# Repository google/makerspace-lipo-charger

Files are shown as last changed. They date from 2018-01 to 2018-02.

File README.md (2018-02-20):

This is in the early stages of prototyping a multi-port 1S Li-po charger.

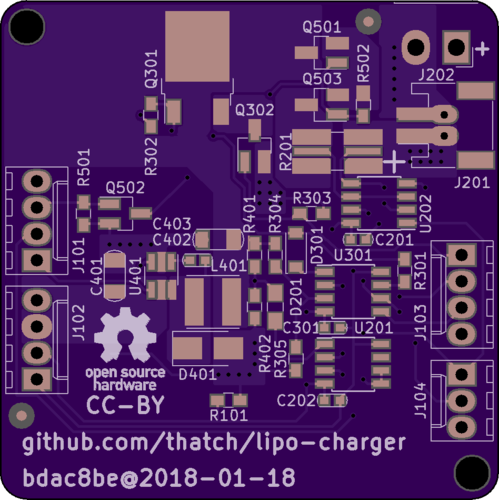
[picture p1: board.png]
Board render


Features include:

- Wide input voltage (approx 5-24V, untested)
- High charge current (up to ~2.5A, untested)
- Discharge circuit (to arbitrary voltage; connector is limiting factor --
  mosfet can do ~10A)
- (Upstream) microcontroller only involved in the slow loops ("is it charged
  yet?", not "is current limit hit?")
- Relatively inexpensive BOM (compared to all-in-one buck-based chargers)
- Relatively easy to solder (only one part smaller than SO-8 and 0603, no exposed pads)

Open questions:

- Do we need extra soft-start circuitry to avoid current spike at beginning of charge?
- Can we heatsink the discharge circuit so this stacks better (DPAK on back ground plane)?
- How small can we get this as a replaceable daughterboard?
- How will we mount it inside a case?
- Can we trust the sum of individual shunts for calculating used power budget?
- How will MCU stay alive while probing (or backing off)
- Is there a much better way to shut off discharge (second nmos is obvious, but expensive)

License: CC-BY 4.0 International

Disclaimer: This not an official Google product.

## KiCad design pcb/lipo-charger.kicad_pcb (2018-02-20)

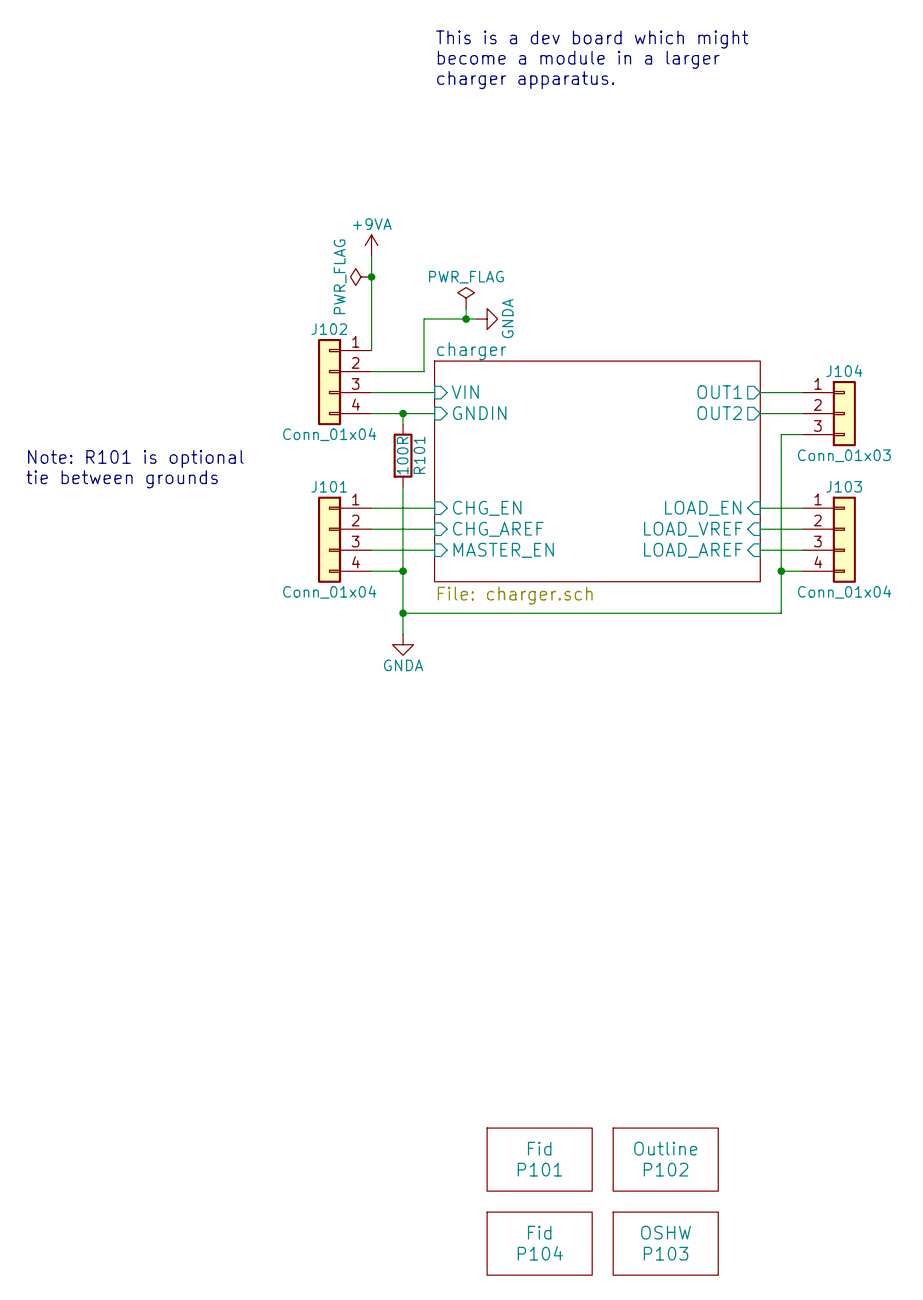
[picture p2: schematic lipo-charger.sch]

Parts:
J101, J102, J103: Conn_01x04; Molex_KK-6410-04_04x2.54mm_Straight
J104: Conn_01x03; Molex_KK-6410-03_03x2.54mm_Straight
P101, P104: Fid; Fiducial_1mm_Dia_2.54mm_Outer_CopperTop
P102: Outline; Board_Outline_48mm_Square
P103: OSHW; OSHW-Logo_7.5x8mm_SilkScreen
R101: 100R; R_0603_HandSoldering

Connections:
+9VA: J102.1; also elsewhere on the board
/charger/CHG_AREF: J101.2; also elsewhere on the board
/charger/CHG_EN: J101.1; also elsewhere on the board
/charger/GNDIN: J102.4, R101.1; also elsewhere on the board
/charger/LOAD_AREF: J103.3; also elsewhere on the board
/charger/LOAD_EN: J103.1; also elsewhere on the board
/charger/LOAD_VREF: J103.2; also elsewhere on the board
/charger/MASTER_EN: J101.3; also elsewhere on the board
/charger/OUT1: J104.1; also elsewhere on the board
/charger/OUT2: J104.2; also elsewhere on the board
/charger/VIN: J102.3; also elsewhere on the board
GNDA: J101.4, J102.2, J103.4, J104.3, R101.2; also elsewhere on the board

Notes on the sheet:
Note: R101 is optional tie between grounds
This is a dev board which might become a module in a larger charger apparatus.

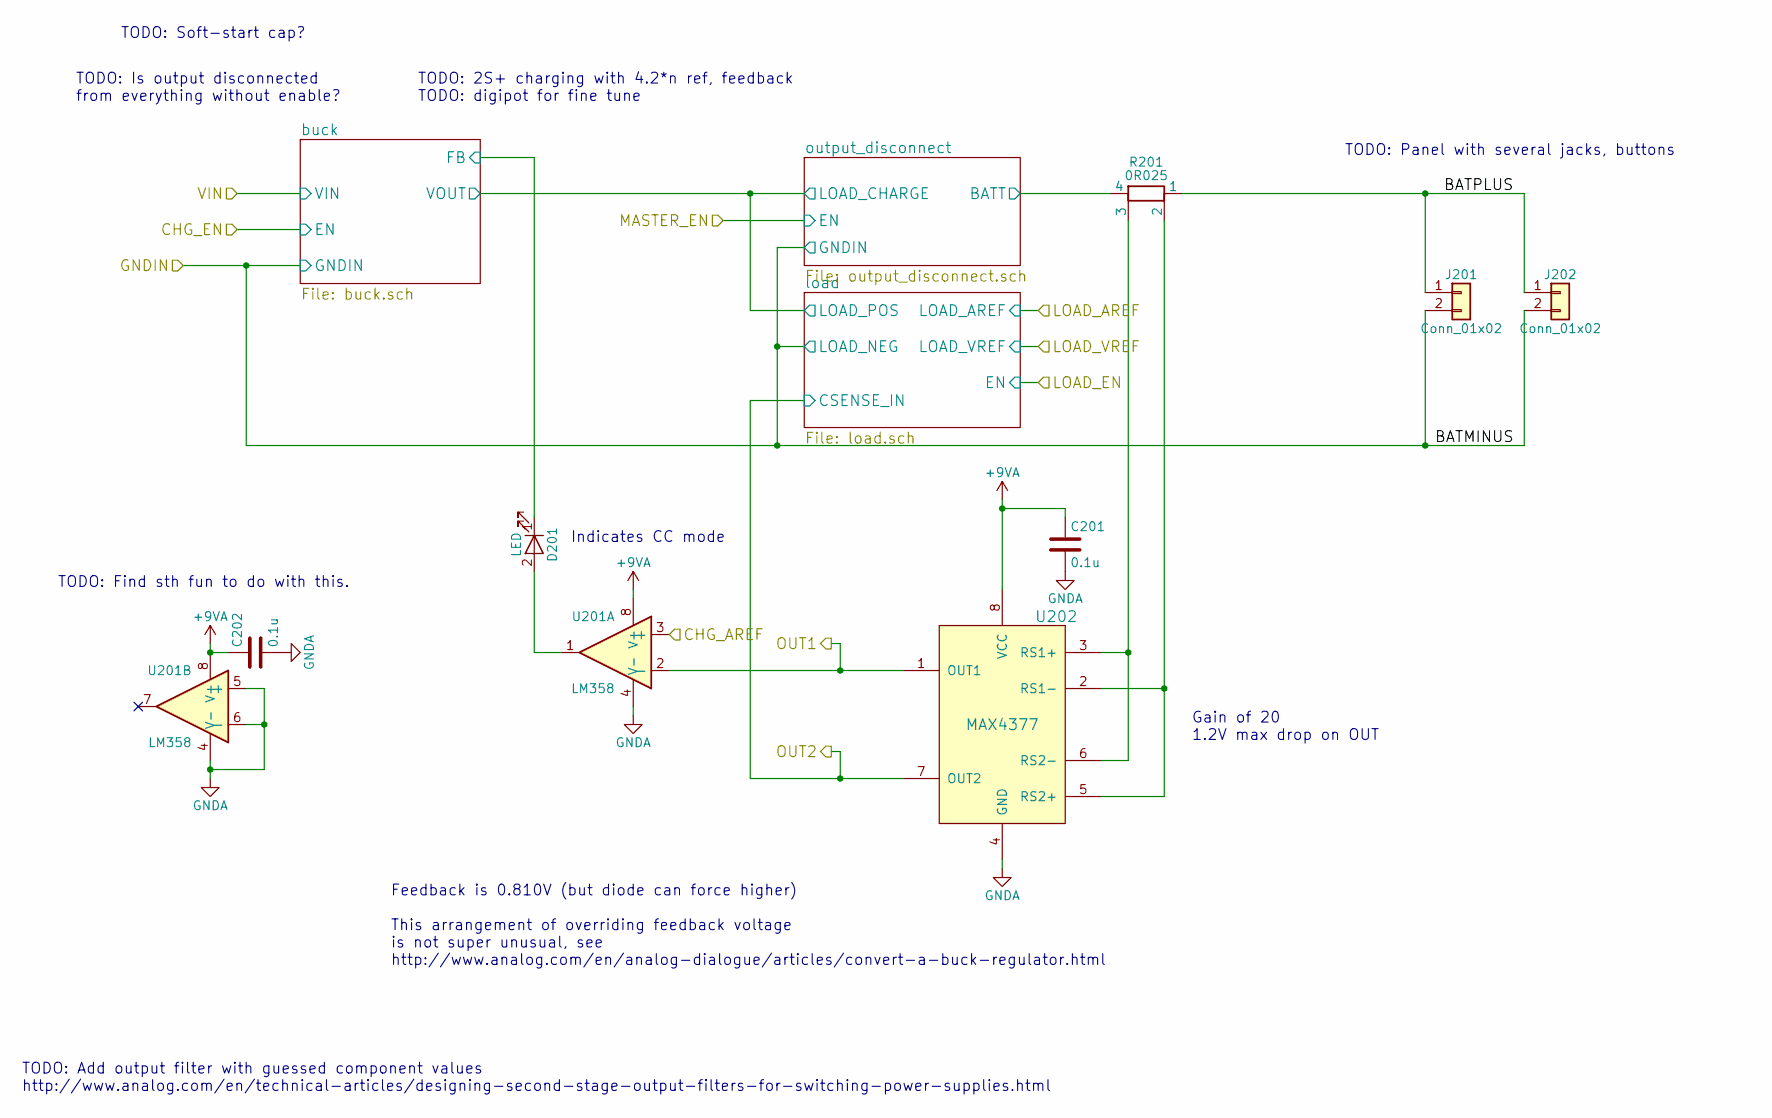
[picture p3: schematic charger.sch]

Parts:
C201, C202: 0.1u; C_0603
D201: LED; LED_0805_HandSoldering
J201: Conn_01x02; JST_PH_2_Combo
J202: Conn_01x02; JST_VH_B2PS-VH_2x2x3.96mm_Horizontal
R201: 0R025; R_2512_AD_Optimized
U201: LM358; SOIC-8_3.9x4.9mm_Pitch1.27mm
U202: MAX4377; SOIC-8_3.9x4.9mm_Pitch1.27mm; MPN MAX4377TASA+

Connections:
+9VA: C201.1, C202.1, U201.8 (V+), U202.8 (VCC); also elsewhere on the board
/charger/BATPLUS: J201.1, J202.1, R201.1
/charger/CHG_AREF: U201.3 (+); also elsewhere on the board
/charger/GNDIN: J201.2, J202.2; also elsewhere on the board
/charger/OUT1: U201.2 (-), U202.1 (OUT1); also elsewhere on the board
/charger/OUT2: U202.7 (OUT2); also elsewhere on the board
/charger/buck/FB: D201.1 (K); also elsewhere on the board
/charger/output_disconnect/BATT: R201.4; also elsewhere on the board
GNDA: C201.2, C202.2, U201.4 (V-), U201.5 (+), U201.6 (-), U202.4 (GND); also elsewhere on the board
unnamed: D201.2 (A), U201.1
unnamed: R201.2, U202.2 (RS1-), U202.5 (RS2+)
unnamed: R201.3, U202.3 (RS1+), U202.6 (RS2-)

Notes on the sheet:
Feedback is 0.810V (but diode can force higher) This arrangement of overriding feedback voltage is not super unusual, see http://www.analog.com/en/analog-dialogue/articles/convert-a-buck-regulator.html
TODO: Add output filter with guessed component values http://www.analog.com/en/technical-articles/designing-second-stage-output-filters-for-switching-power-supplies.html
TODO: Panel with several jacks, buttons
Indicates CC mode
TODO: Soft-start cap?
TODO: Is output disconnected from everything without enable?
Gain of 20 1.2V max drop on OUT
TODO: 2S+ charging with 4.2*n ref, feedback TODO: digipot for fine tune
TODO: Find sth fun to do with this.

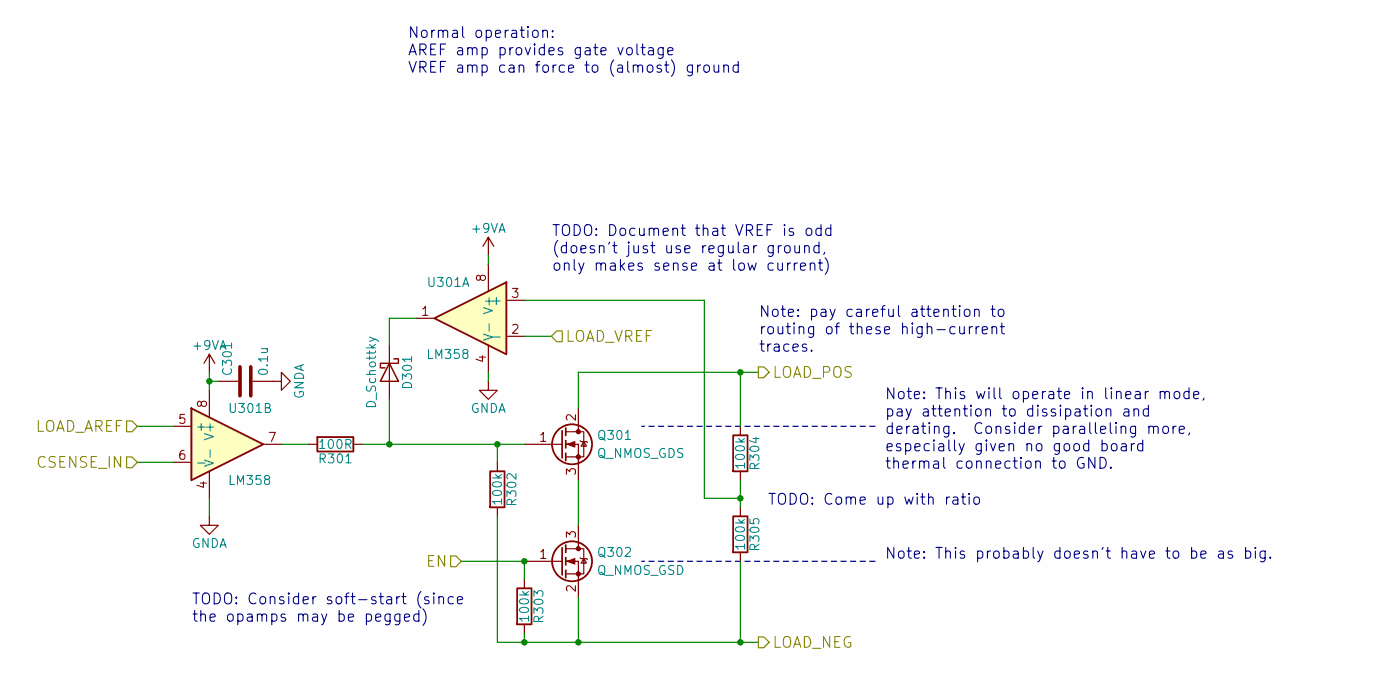
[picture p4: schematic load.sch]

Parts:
C301: 0.1u; C_0603
D301: D_Schottky; D_SOD-123
Q301: Q_NMOS_GDS; TO-252-2; MPN AO514
Q302: Q_NMOS_GSD; SOT-23_Handsoldering; MPN AO3400
R301: 100R; R_0603_HandSoldering
R302, R303, R304, R305: 100k; R_0603_HandSoldering
U301: LM358; SOIC-8_3.9x4.9mm_Pitch1.27mm

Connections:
+9VA: C301.1, U301.8 (V+); also elsewhere on the board
/charger/GNDIN: Q302.2 (S), R302.2, R303.2, R305.2; also elsewhere on the board
/charger/LOAD_AREF: U301.5 (+); also elsewhere on the board
/charger/LOAD_EN: Q302.1 (G), R303.1; also elsewhere on the board
/charger/LOAD_VREF: U301.2 (-); also elsewhere on the board
/charger/OUT2: U301.6 (-); also elsewhere on the board
/charger/output_disconnect/LOAD_CHARGE: Q301.2 (D), R304.1; also elsewhere on the board
GNDA: C301.2, U301.4 (V-); also elsewhere on the board
unnamed: D301.1 (K), U301.1
unnamed: D301.2 (A), Q301.1 (G), R301.1, R302.1
unnamed: Q301.3 (S), Q302.3 (D)
unnamed: R301.2, U301.7
unnamed: R304.2, R305.1, U301.3 (+)

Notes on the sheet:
Note: pay careful attention to routing of these high-current traces.
Normal operation: AREF amp provides gate voltage VREF amp can force to (almost) ground
Note: This will operate in linear mode, pay attention to dissipation and derating. Consider paralleling more, especially given no good board thermal connection to GND.
Note: This probably doesn't have to be as big.
TODO: Come up with ratio
TODO: Consider soft-start (since the opamps may be pegged)
TODO: Document that VREF is odd (doesn't just use regular ground, only makes sense at low current)

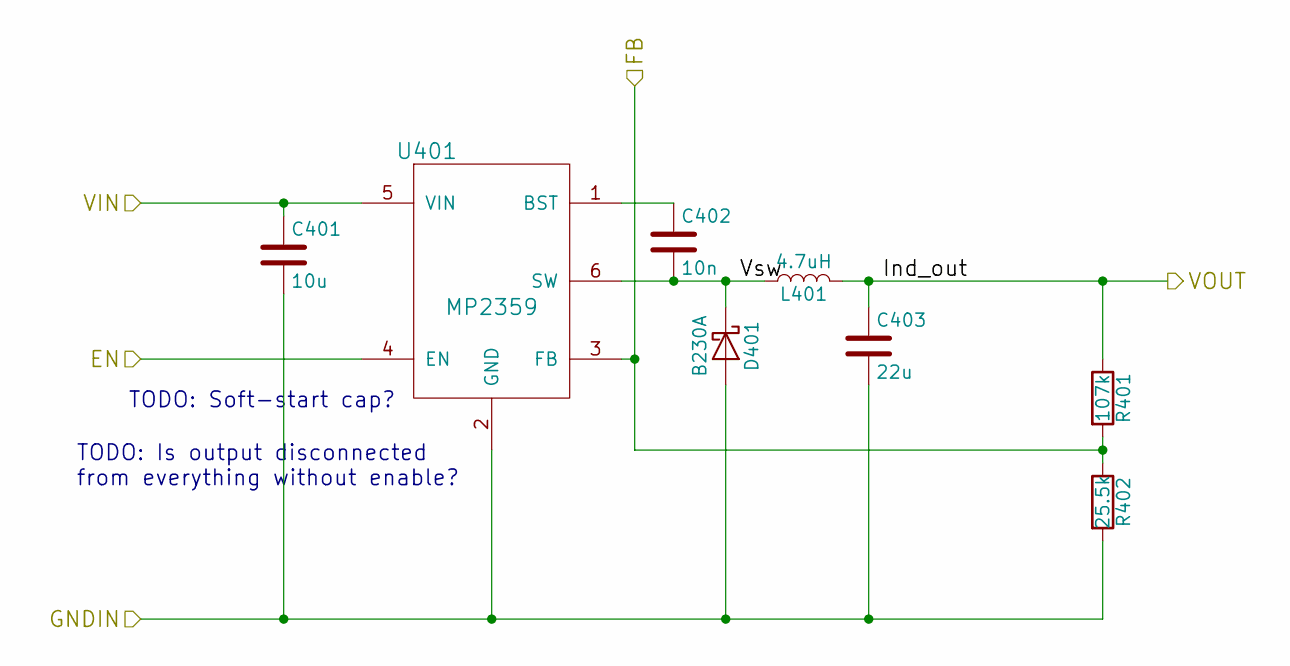
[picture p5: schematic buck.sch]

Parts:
C401: 10u; C_1206
C402: 10n; C_0603
C403: 22u; C_1206
D401: B230A; D_SMA
L401: 4.7uH; L_Taiyo-Yuden_NR-50xx
R401: 107k; R_0603_HandSoldering
R402: 25.5k; R_0603_HandSoldering
U401: MP2359; SOT-23-6_Handsoldering

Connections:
/charger/CHG_EN: U401.4 (EN); also elsewhere on the board
/charger/GNDIN: C401.2, C403.2, D401.2 (A), R402.2, U401.2 (GND); also elsewhere on the board
/charger/VIN: C401.1, U401.5 (VIN); also elsewhere on the board
/charger/buck/FB: R401.2, R402.1, U401.3 (FB); also elsewhere on the board
/charger/buck/Vsw: C402.2, D401.1 (K), L401.1, U401.6 (SW)
/charger/output_disconnect/LOAD_CHARGE: C403.1, L401.2, R401.1; also elsewhere on the board
unnamed: C402.1, U401.1 (BST)

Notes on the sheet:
TODO: Soft-start cap?
TODO: Is output disconnected from everything without enable?

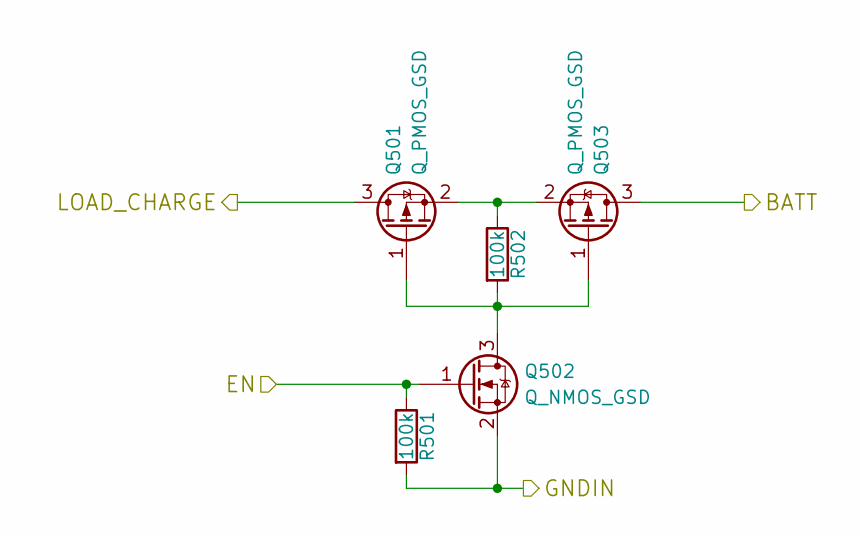
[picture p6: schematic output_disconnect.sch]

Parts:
Q501, Q503: Q_PMOS_GSD; SOT-23_Handsoldering
Q502: Q_NMOS_GSD; SOT-23_Handsoldering
R501, R502: 100k; R_0603_HandSoldering

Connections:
/charger/GNDIN: Q502.2 (S), R501.2; also elsewhere on the board
/charger/MASTER_EN: Q502.1 (G), R501.1; also elsewhere on the board
/charger/output_disconnect/BATT: Q503.3 (D); also elsewhere on the board
/charger/output_disconnect/LOAD_CHARGE: Q501.3 (D); also elsewhere on the board
unnamed: Q501.1 (G), Q502.3 (D), Q503.1 (G), R502.2
unnamed: Q501.2 (S), Q503.2 (S), R502.1

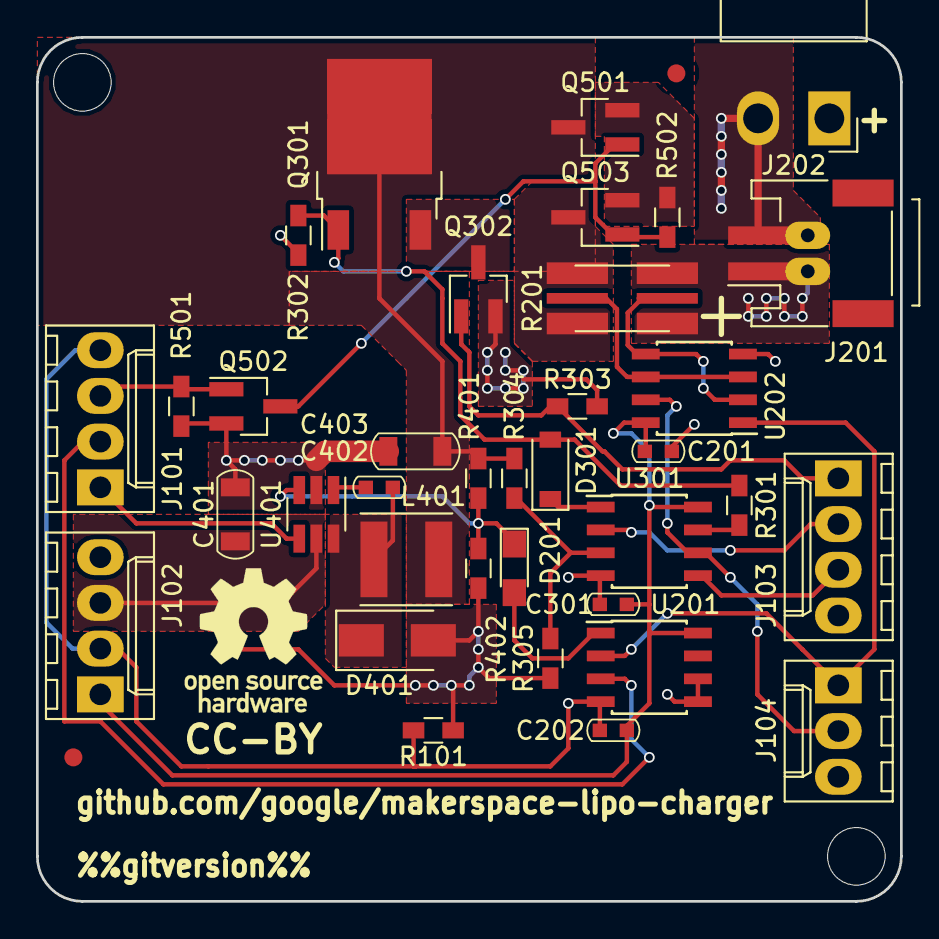
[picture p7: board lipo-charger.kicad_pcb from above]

Board: 2 copper layers, 48.0 x 48.0 mm, 40 parts (0 on the bottom side), 28 nets.

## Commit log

2017-12-22 Initial board, with relative paths
    [charger.sch, lipo-charger.kicad_pcb, lipo-charger.sch]
2017-12-22 Fix ERC/DRC errors for first prototype
    [charger.sch, lipo-charger.sch]
2017-12-30 Massive rework, fully routed
    [buck.sch, charger.sch, lipo-charger.kicad_pcb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]
2017-12-30 Add gitversion to pcb, minor tweaks
    [lipo-charger.kicad_pcb]
2018-01-18 Rename some nets, ordered.
    [charger.sch, lipo-charger.kicad_pcb, lipo-charger.sch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]
2018-01-31 Add board render
2018-02-20 Fixup url and add license
    [buck.sch, charger.sch, lipo-charger.kicad_pcb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]
